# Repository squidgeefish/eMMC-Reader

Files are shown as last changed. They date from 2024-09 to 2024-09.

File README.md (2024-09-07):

# eMMC-Reader
A GL3224-based eMMC reader

## Why?

The Sabrent USB readers that had this chip were recently (2022?) updated to use the 48-QFN version with dual LUNs. This happened to break the single-bit eMMC mode, and that makes me very sad. Rather than trawling eBay for NOS packaging, I figured I should just make a better tool.

This also includes a TXS02612 that is being used as a 1.8V level shifter like on an Exploitee.rs [Low Voltage eMMC Adapter](https://shop.exploitee.rs/shop/p/low-voltage-emmc-adapter) because those are great.\
Note that this is a mux, which isn't necessary in this application. I could wire it up to an SD card socket, but that's overkill. According to [TI's Product Overview for SDIO voltage translators](https://www.ti.com/lit/an/scea096/scea096.pdf), the TXS0206 is a non-mux version of this, but it only supports 60Mbps (as opposed to 120Mbps) and is a WCSP. I've gotten more than 60Mbps out of an exploitee.rs board in single-bit mode, so I'm going to stick with the proven chip.

#### Why not USB-C?
Because I don't trust you not to break it...

The GL3224 supports USB 3.0 (5Gbps). To implement that with a USB-C connector, there are two options:
1. Use a plug and hook up one pair of `SS[R,T]X` lines as well as a 5K1 pulldown on CC1. The computer into which this is plugged will have to figure out which pair is live.
2. Use a receptacle and include a SuperSpeed-capable mux like an `HD3SS3220` since you can't trust a user to plug the cable in the "right" way.

USB-C plugs suck because they need thin PCBs and you will break one off in your computer at some point. Unless you use a (technically illegal) extension cable, and then we're back to the same impasse as we had with the receptacle in the first place. It's easier and more robust to use a USB 3.0 Type-A connector (I typically wind up using the Sabrent USB reader with a USB 2.0 extension cable anyway to keep the clock speeds down).

## Links

- [Somebody who reversed a GL3224 adapter](https://www.801labs.org/research-portal/post/reverse-engineering-4-layer-pcb/)
- [Sample (reverse-engineered as above) schematic](https://github.com/dvdfreitag/USB3-eMMC)
- [Eagle Library for the 48- and 32-QFN parts](https://github.com/dvdfreitag/eagle_libraries/blob/bc423563c25ef42febea000f4a0536ccb97d0efd/GenesysLogic.lbr)

Note that this schematic is a little more grand than the bare minimum necessary; the Sabrent reader that inspired this project doesn't bother with the external oscillator.

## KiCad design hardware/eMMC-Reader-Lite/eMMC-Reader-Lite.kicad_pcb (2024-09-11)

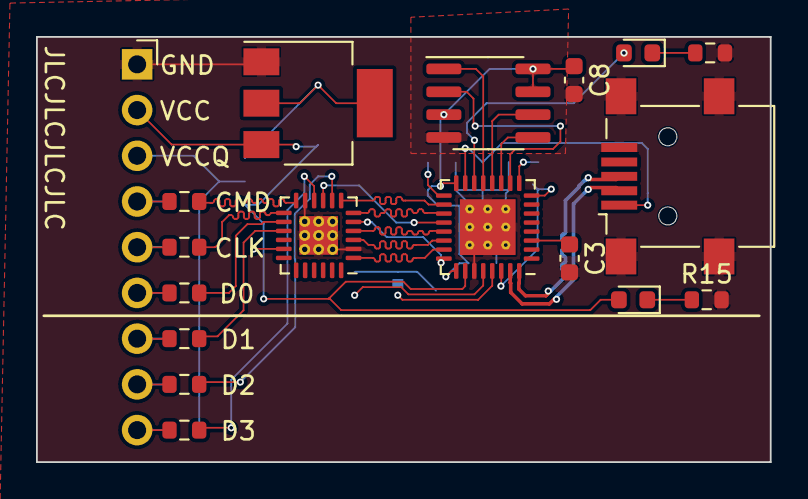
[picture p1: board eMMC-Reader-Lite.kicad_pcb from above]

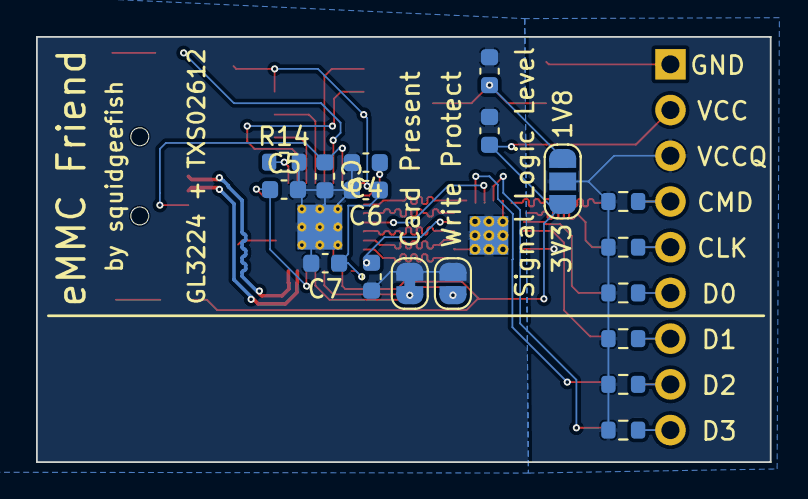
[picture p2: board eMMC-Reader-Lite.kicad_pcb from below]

Board: 2 copper layers, 40.8 x 23.6 mm, 36 parts (18 on the bottom side), 40 nets.

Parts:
C1, C3, C6, C7, C8: 0.1uF; C_0603_1608Metric
C4, C5: 1uF; C_0603_1608Metric
C9: 2.2uF; C_0603_1608Metric
C10, C11: 4.7uF; C_0603_1608Metric
D1, D2: LED_Small_Filled; LED_0603_1608Metric
J1: Conn_01x09_Socket; PinSocket_1x09_P2.54mm_Horizontal
J2: USB_B_Mini; USB_Mini-B_Lumberg_2486_01_Horizontal
JP1: SolderJumper_2_Open; SolderJumper-2_P1.3mm_Open_RoundedPad1.0x1.5mm
JP2: SolderJumper_2_Bridged; SolderJumper-2_P1.3mm_Bridged_RoundedPad1.0x1.5mm
JP3: SolderJumper_3_Open; SolderJumper-3_P1.3mm_Open_RoundedPad1.0x1.5mm
R1, R2, R3, R4, R5, R6: 0; R_0603_1608Metric
R7, R8, R9, R10, R11, R12: 47; R_0603_1608Metric
R13, R15: 220; R_0603_1608Metric
R14: 680; R_0603_1608Metric
U1: QFN-32-1EP_5x5mm_P0.5mm_EP3.1x3.1mm_ThermalVias
U2: TXS02612; QFN-24-1EP_4x4mm_P0.5mm_EP2.15x2.15mm_ThermalVias
U3: W25X20CLSN; SOIC-8_3.9x4.9mm_P1.27mm
U4: LM1117MP-1.8; SOT-223-3_TabPin2

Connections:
+1V8: C11.1, JP3.1 (A), U4.2 (VO)
+3V3: C6.1, C7.1, C8.1, U1.16 (DVDD33), U1.25 (DVDD33), U3.3 (~WP), U3.7 (~HOLD), U3.8 (VCC)
/D+: J2.3 (D+), U1.32 (D+)
/D-: J2.2 (D-), U1.31 (D-)
/SD_CD#: JP2.1 (A), U1.29 (SD_CDZ)
/SD_VCC: C10.1, D2.2 (A), J1.2, JP3.3 (B), U1.26 (SD_VCC), U4.3 (VI)
/SD_WP: JP1.1 (A), U1.28 (SD_WP)
/VCCA: C1.1, U1.24 (SD_VCCQ), U2.5 (VCCA), U2.24 (SEL)
GND: C1.2, C3.2, C4.2, C5.2, C6.2, C7.2, C8.2, C9.2, C10.2, C11.2, J1.1, J2.5 (GND), J2.6 (Shield), JP1.2 (B), JP2.2 (B), R13.2, R14.2, R15.2, U1.27 (GND), U1.33 (GND), U2.2 (GND), U2.11 (GND), U2.25 (GND), U3.4 (GND), U4.1 (GND)
unnamed: C5.1, U1.8 (AVDD33), U1.30 (AVDD33)
unnamed: D1.2 (A), U1.14 (LED)
unnamed: D1.1 (K), R13.1
unnamed: D2.1 (K), R15.1
unnamed: J1.4, R1.2, R12.1
unnamed: J1.5, R2.2, R11.1
unnamed: J1.6, R3.2, R10.1
unnamed: J1.7, R4.2, R9.1
unnamed: J1.8, R5.2, R8.1
unnamed: J1.9, R6.2, R7.1
unnamed: R14.1, U1.9 (RTERM)
unnamed: U1.20 (SD_CLK), U2.9 (CLKA)
unnamed: U1.21 (SD_CMD), U2.4 (CMDA)
unnamed: U1.19 (SD_D0), U2.6 (DAT0A)
unnamed: U1.18 (SD_D1), U2.7 (DAT1A)
unnamed: U1.23 (SD_D2), U2.1 (DAT2A)
unnamed: U1.22 (SD_D3), U2.3 (DAT3A)
unnamed: U1.12 (SPI_CK), U3.6 (SCK)
unnamed: U1.13 (SPI_CS), U3.1 (~CS)
unnamed: U1.10 (SPI_MISO), U3.2 (DO(IO1))
unnamed: U1.11 (SPI_MOSI), U3.5 (DI(IO0))
unnamed: C3.1, U1.3 (AVDD12)
unnamed: C4.1, U1.17 (DVDD12)
unnamed: R2.1, U2.13 (CLKB_1)
unnamed: R1.1, U2.12 (CMDB_1)
unnamed: R3.1, U2.14 (DAT0B_1)
unnamed: R4.1, U2.15 (DAT1B_1)
unnamed: R5.1, U2.8 (DAT2B_1)
unnamed: R6.1, U2.10 (DAT3B_1)
VBUS: C9.1, J2.1 (VBUS), U1.15 (VBUS)
VCCQ: J1.3, JP3.2 (C), R7.2, R8.2, R9.2, R10.2, R11.2, R12.2, U2.17 (VCCB_1)

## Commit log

2024-09-07 Mostly done with schematic
    [eMMC-Reader.kicad_pcb, eMMC-Reader.kicad_sch]
2024-09-07 Finish up schematic (added switches and regulators); just some power caps to go
    [eMMC-Reader.kicad_sch]
2024-09-08 Finish schematic; partial layout for fully-featured board
    [eMMC-Reader.kicad_pcb, eMMC-Reader.kicad_sch]
2024-09-10 Make stripped-down 'eMMC Friend'-style schematic and layout
    [eMMC-Reader-Lite.kicad_pcb, eMMC-Reader-Lite.kicad_sch]
2024-09-11 Add yellow fill to symbols; add GL3224 pin 27 (GND)
2024-09-11 Further routing
    Need fills, GL3224 test points, length-matching from GL3224
    Might need more blinky
    [eMMC-Reader-Lite.kicad_pcb, eMMC-Reader-Lite.kicad_sch]
2024-09-11 Break out SD_VCC output rail to be distinct from 3V3 net
    Add indicator LED for that rail
    [eMMC-Reader-Lite.kicad_pcb, eMMC-Reader-Lite.kicad_sch]
2024-09-11 Fix swapped USB data lines
    [eMMC-Reader-Lite.kicad_pcb, eMMC-Reader-Lite.kicad_sch]
2024-09-11 Basic routing (needs properly-sized traces, cleaner copper pours)
    [eMMC-Reader-Lite.kicad_pcb]
